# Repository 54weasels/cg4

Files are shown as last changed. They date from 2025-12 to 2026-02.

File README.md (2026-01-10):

# Sun CG/4
From [Frame Buffer History Lesson](https://www.sunhelp.org/faq/FrameBufferHistory.html):
```
cg4: device name: "/dev/cgfour0"  
```
Project name: Prism The dumb 8-bit color frame buffer with overlay and enable planes. Found in 3/110C, 3/60C, 4/110C and 4/150C. This is the first one using the "P4" bus.

The 10-bit deep frame buffer found on the CPU board of the Sun-3/110, and as an option to the Sun-3/60 and Sun-4/110. The 10 bits on the frame buffer are: 8-bits color frame buffer, 1 bit monochrome frame buffer and 1 bit enable plane, which determines which bits of the colour and mono planes are displayed.

For a Sun-4/110, Sun-3/60 and other machines with a P4 connector the CG4 frame buffer is a daughter-board. Note that no GP can be added to the CG4. There is no rasterop hardware on the CG4 frame buffer. The CG4 will "probably" be on all desktop P4 type products. The device driver for the CG4 is called "cgfour".

```
device cgfour0 at obmem 7 csr 0xff300000 priority 4  
```
This is the P4 bus color frame buffer for the 3/60 and 4/110

Resolution is **1152x900**

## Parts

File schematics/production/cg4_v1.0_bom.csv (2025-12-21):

Designator | Footprint | Quantity | Value | LCSC Part #
C1, C10, C11, C12, C13, C1306, C14, C15, C16, C17, C18, C19, C2, C20, C21, C22, C23, C24, C25, C26, C27, C28, C29, C3, C30, C31, C32, C33, C34, C35, C36, C37, C38, C39, C4, C40, C5, C6, C7, C8, C9 | C_Rect_L7.0mm_W2.0mm_P5.00mm | 41 | 0.1uF
C1300, C1302, C1303, C1305 | C_Rect_L7.0mm_W2.0mm_P5.00mm | 4 | 0.01 uF
J7 | DSUB-15-HD_Socket_Horizontal_P2.29x2.54mm_EdgePinOffset8.35mm_Housed_MountingHolesOffset10.89mm | 1 | DE15_Socket_HighDensity
K1300 | CP_Radial_D10.0mm_P5.00mm | 1 | 10uF
L1300, L1301 | R_Axial_DIN0309_L9.0mm_D3.2mm_P12.70mm_Horizontal | 2 | L_Small
P4 | DIN41612_R_3x32_Male_Vertical_THT | 1 | DIN41612_03x32_C_Split
R1 | R_Axial_DIN0207_L6.3mm_D2.5mm_P10.16mm_Horizontal | 1 | 0 Ω
R1300 | R_Axial_DIN0207_L6.3mm_D2.5mm_P10.16mm_Horizontal | 1 | 500Ω 1%
R1301 | R_Axial_DIN0207_L6.3mm_D2.5mm_P10.16mm_Horizontal | 1 | 1K 1%
R1302, R1303, R1304 | R_Axial_DIN0207_L6.3mm_D2.5mm_P10.16mm_Horizontal | 3 | 75Ω 1%
R1311, R1312, R1313, R5 | R_Axial_DIN0207_L6.3mm_D2.5mm_P10.16mm_Horizontal | 4 | 330Ω
R1315 | R_Axial_DIN0207_L6.3mm_D2.5mm_P10.16mm_Horizontal | 1 | ? Ω
S1000 | R_Array_SIP10 | 1 | 470Ω
U1000, U1006 | DIP-20_W7.62mm | 2 | PAL16R8
U1001, U1002, U1003 | DIP-24_W7.62mm | 3 | PAL20X10
U1004 | DIP-24_W7.62mm | 1 | PAL20R6
U1005, U1008, U1009, U1010 | DIP-20_W7.62mm | 4 | P16L8
U1007 | DIP-24_W7.62mm | 1 | P20L8
U1015 | DIP-16_W7.62mm | 1 | 74F175
U1016 | DIP-20_W7.62mm | 1 | 74F244
U1017, U1021, U1036, U1037, U1038, U1104, U1105, U1114 | DIP-16_W7.62mm | 8 | 330Ω
U1100, U1101, U1102, U1103, U1110, U1111, U1112, U1113 | DIP-16_W7.62mm | 8 | 74F257
U1129 | DIP-14_W7.62mm | 1 | 74LS393
U1200, U1201, U1202, U1203, U1204, U1205, U1206, U1207, U1208, U1209, U1210, U1211, U1212, U1213, U1214, U1215, U1216, U1217, U1218, U1219, U1220, U1221, U1222, U1223, U1224, U1225, U1226, U1227, U1228, U1229, U1230, U1231, U1300, U1301, U1302, U1303, U1304, U1305, U1306, U1307 | ZIP_24 | 40 | HM53461
U1310 | PGA_84_Pin | 1 | BT458
U1311 | Oscillator_DIP-14 | 1 | 92.9405Mhz
U1312 | DIP-16_W7.62mm | 1 | 10H101
U1313 | DIP-16_W7.62mm | 1 | 10H131
U1314 | DIP-16_W7.62mm | 1 | 10H350
U1315 | TO-92_Inline | 1 | LM385BZ-1.2
U1318 | DIP-14_W7.62mm | 1 | 74F08

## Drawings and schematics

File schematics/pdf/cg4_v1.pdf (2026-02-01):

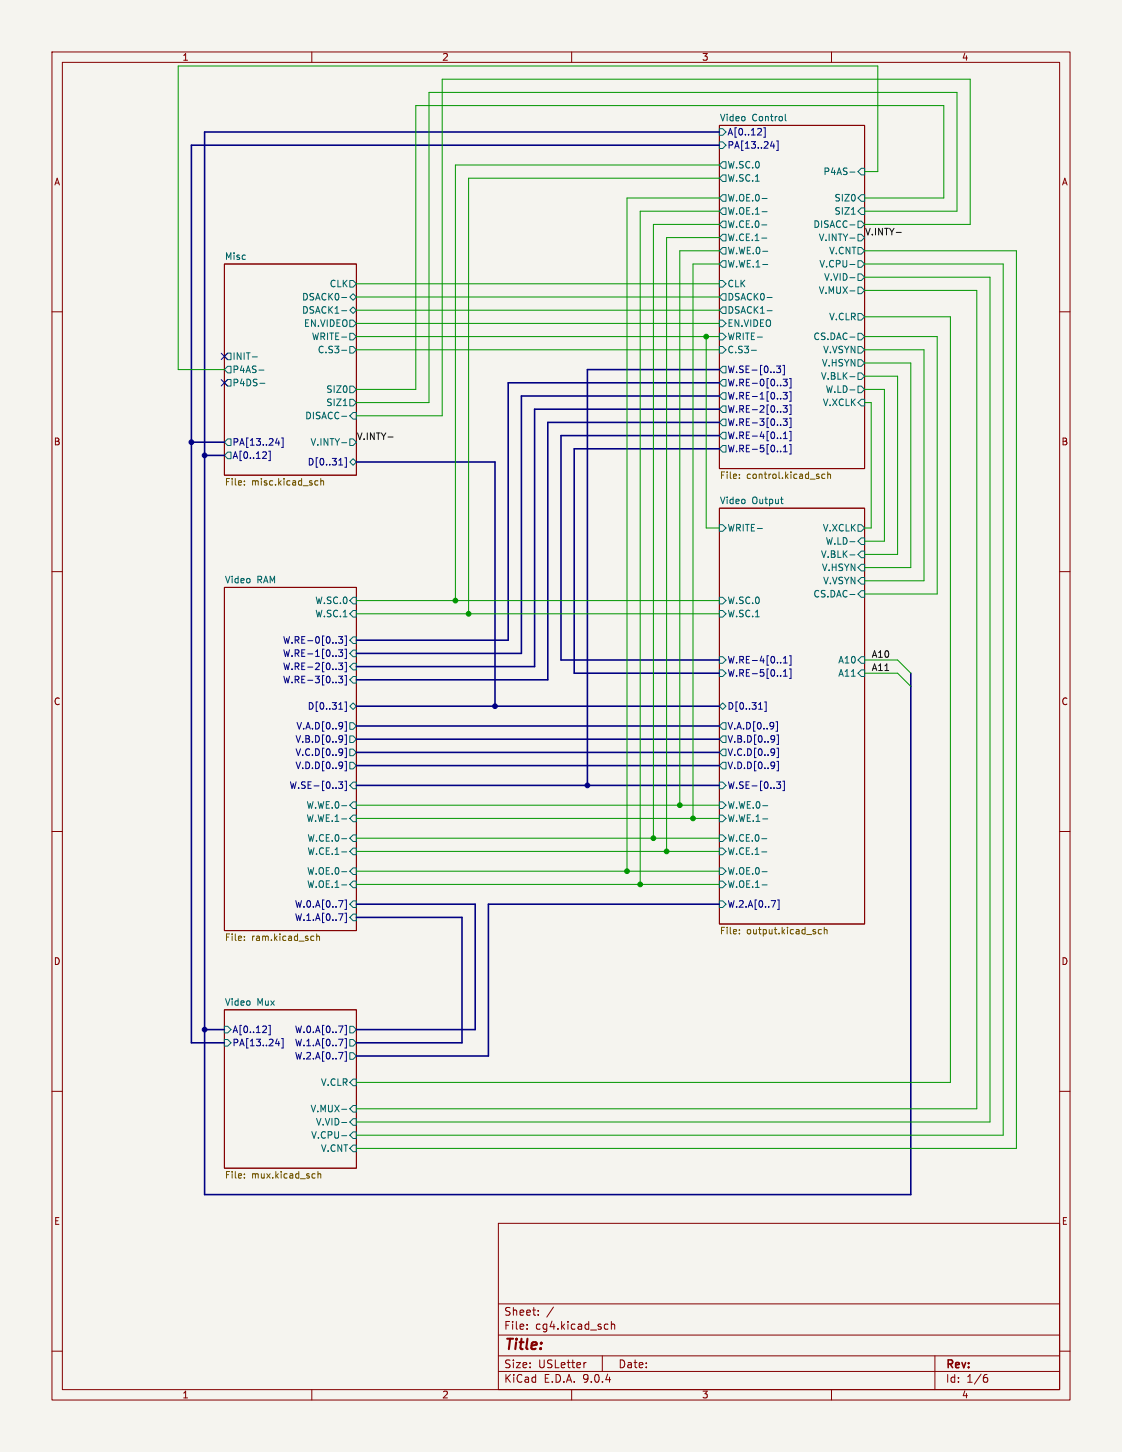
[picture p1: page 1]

V.VSYN
W.RE-5[0..1] W.SC.0 W.SC.1 Video Output File: output.kicad_sch

V.D.D[0..9] Video RAM

Id: 1/6 Title: File: cg4.kicad_sch Sheet: / V.CLR W.0.A[0..7]

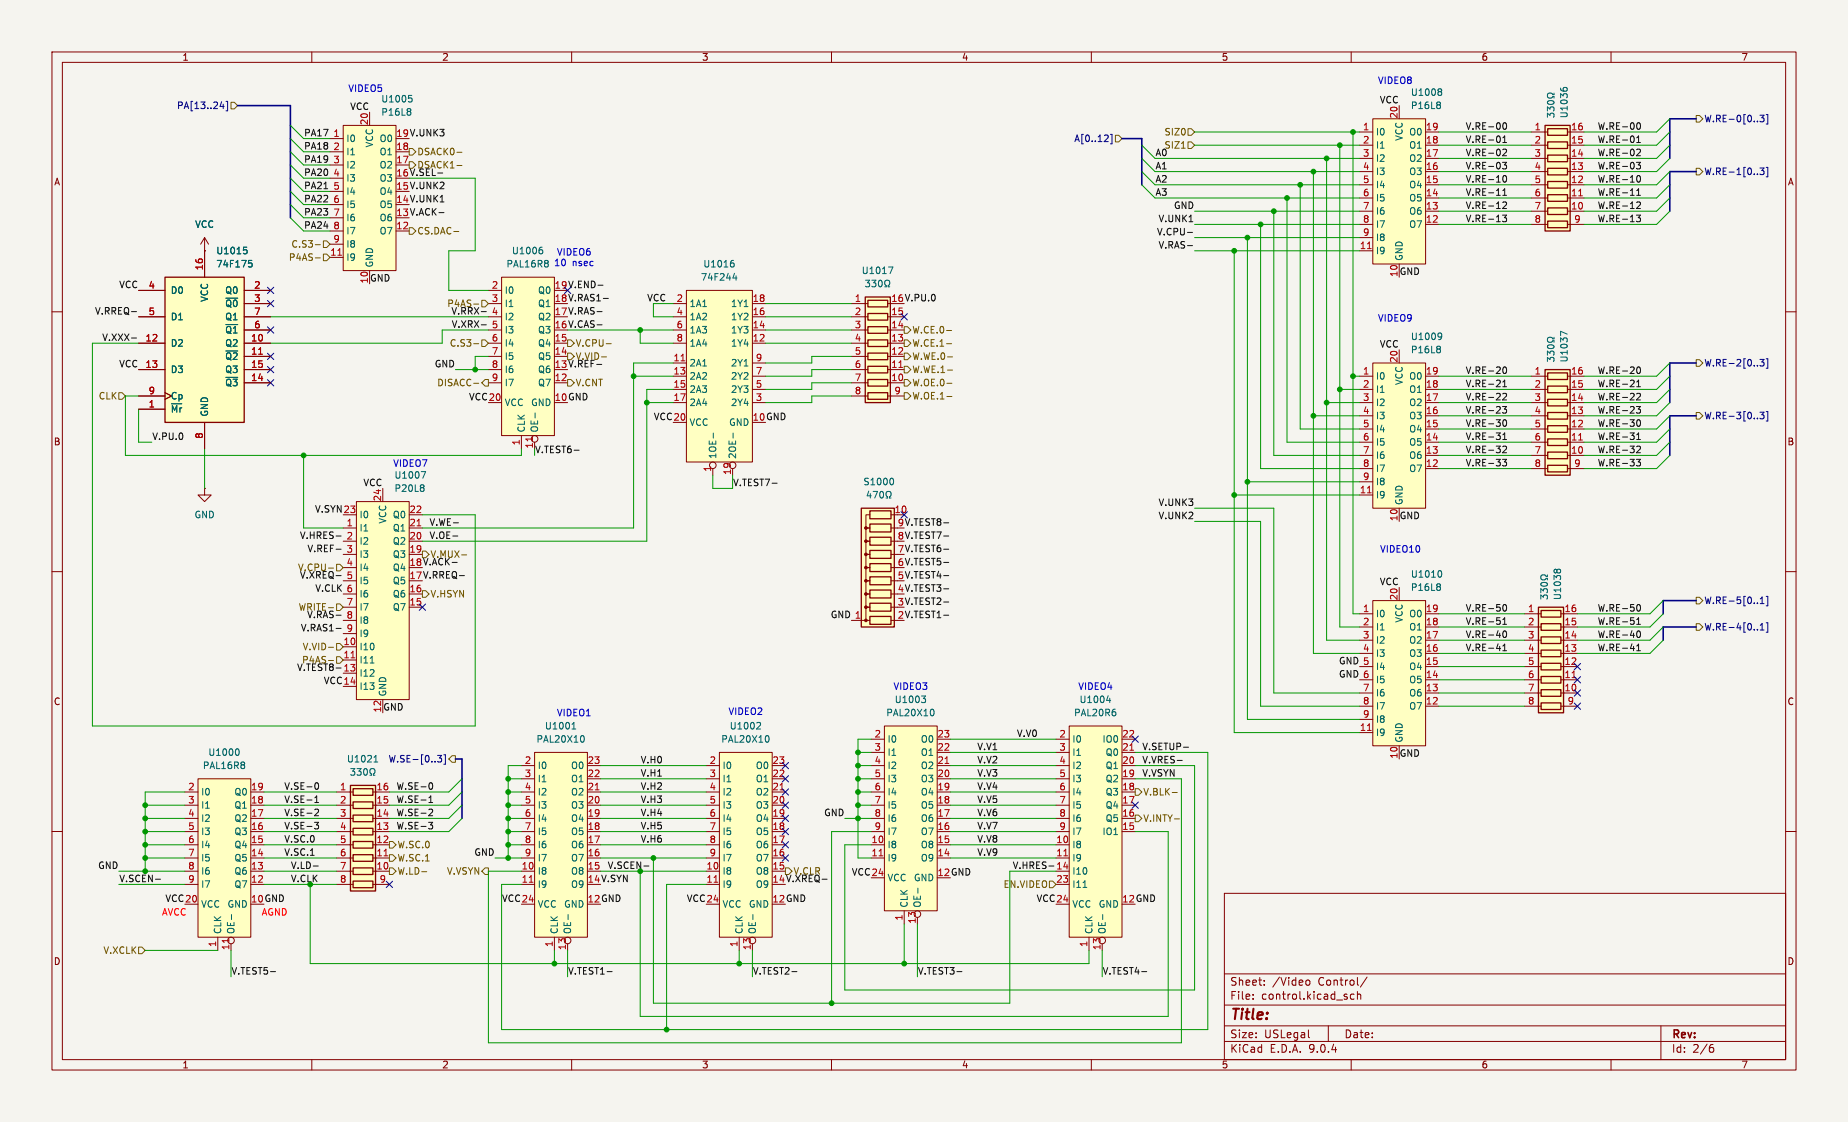
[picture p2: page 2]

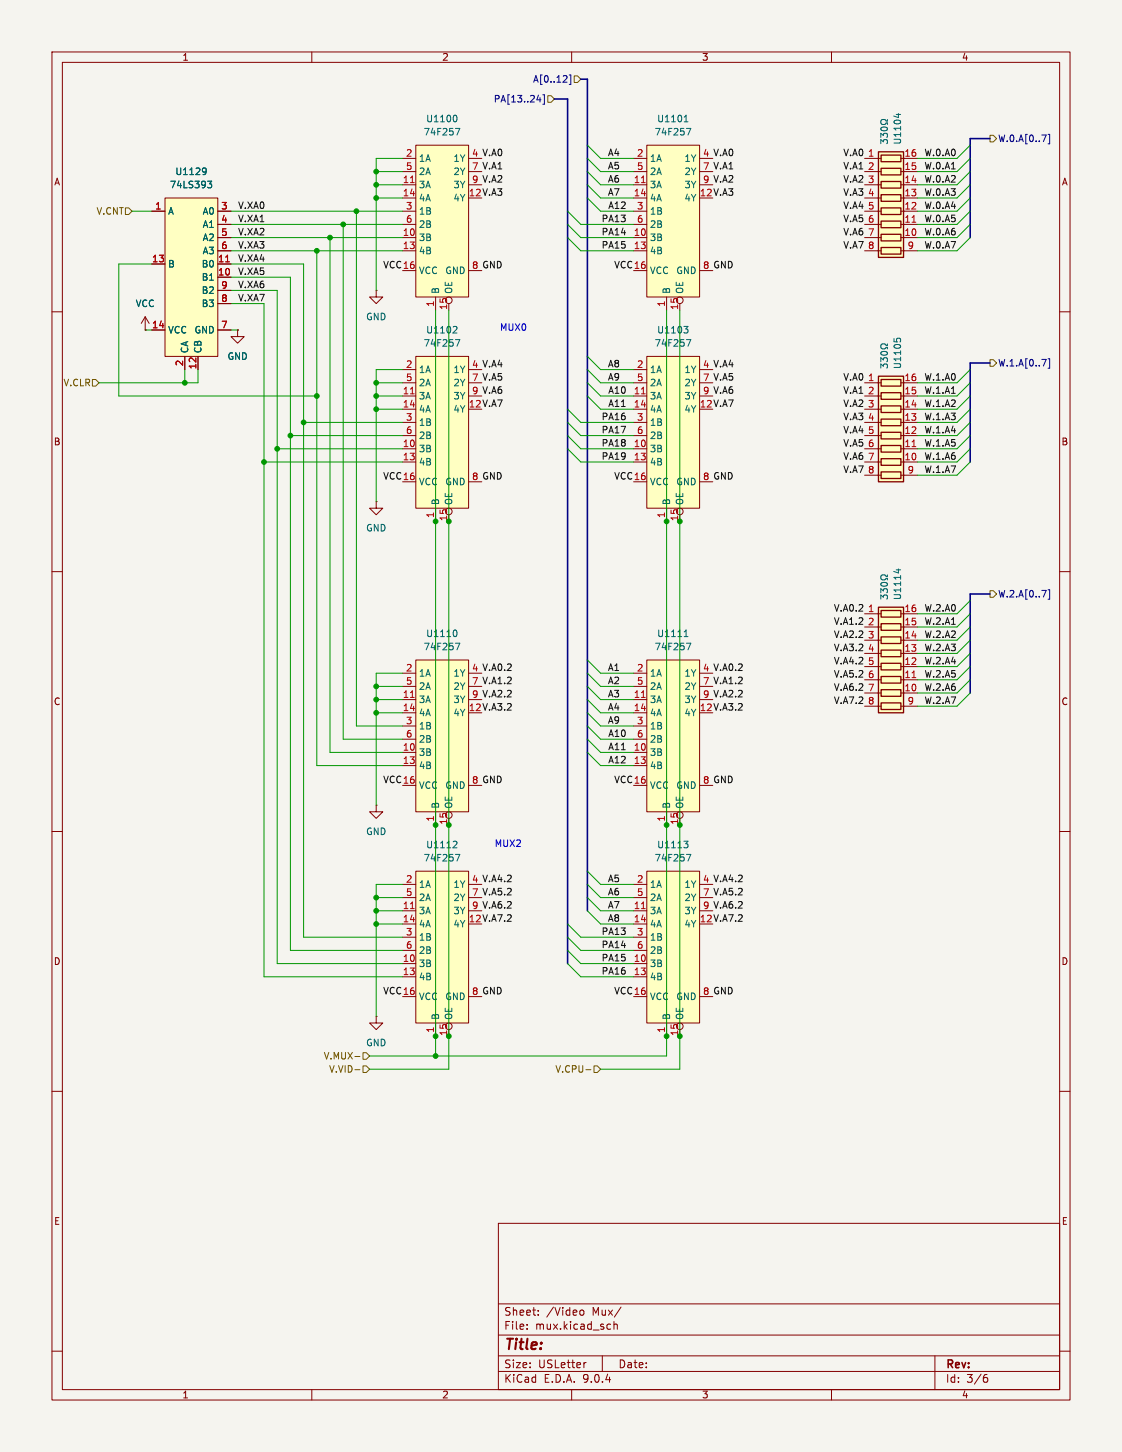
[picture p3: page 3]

2 CB 12 A0 3 A1 4 A2 5 A3 6 B0 11 B1 10 B2 9 B3 8 GND 7 VCC GND

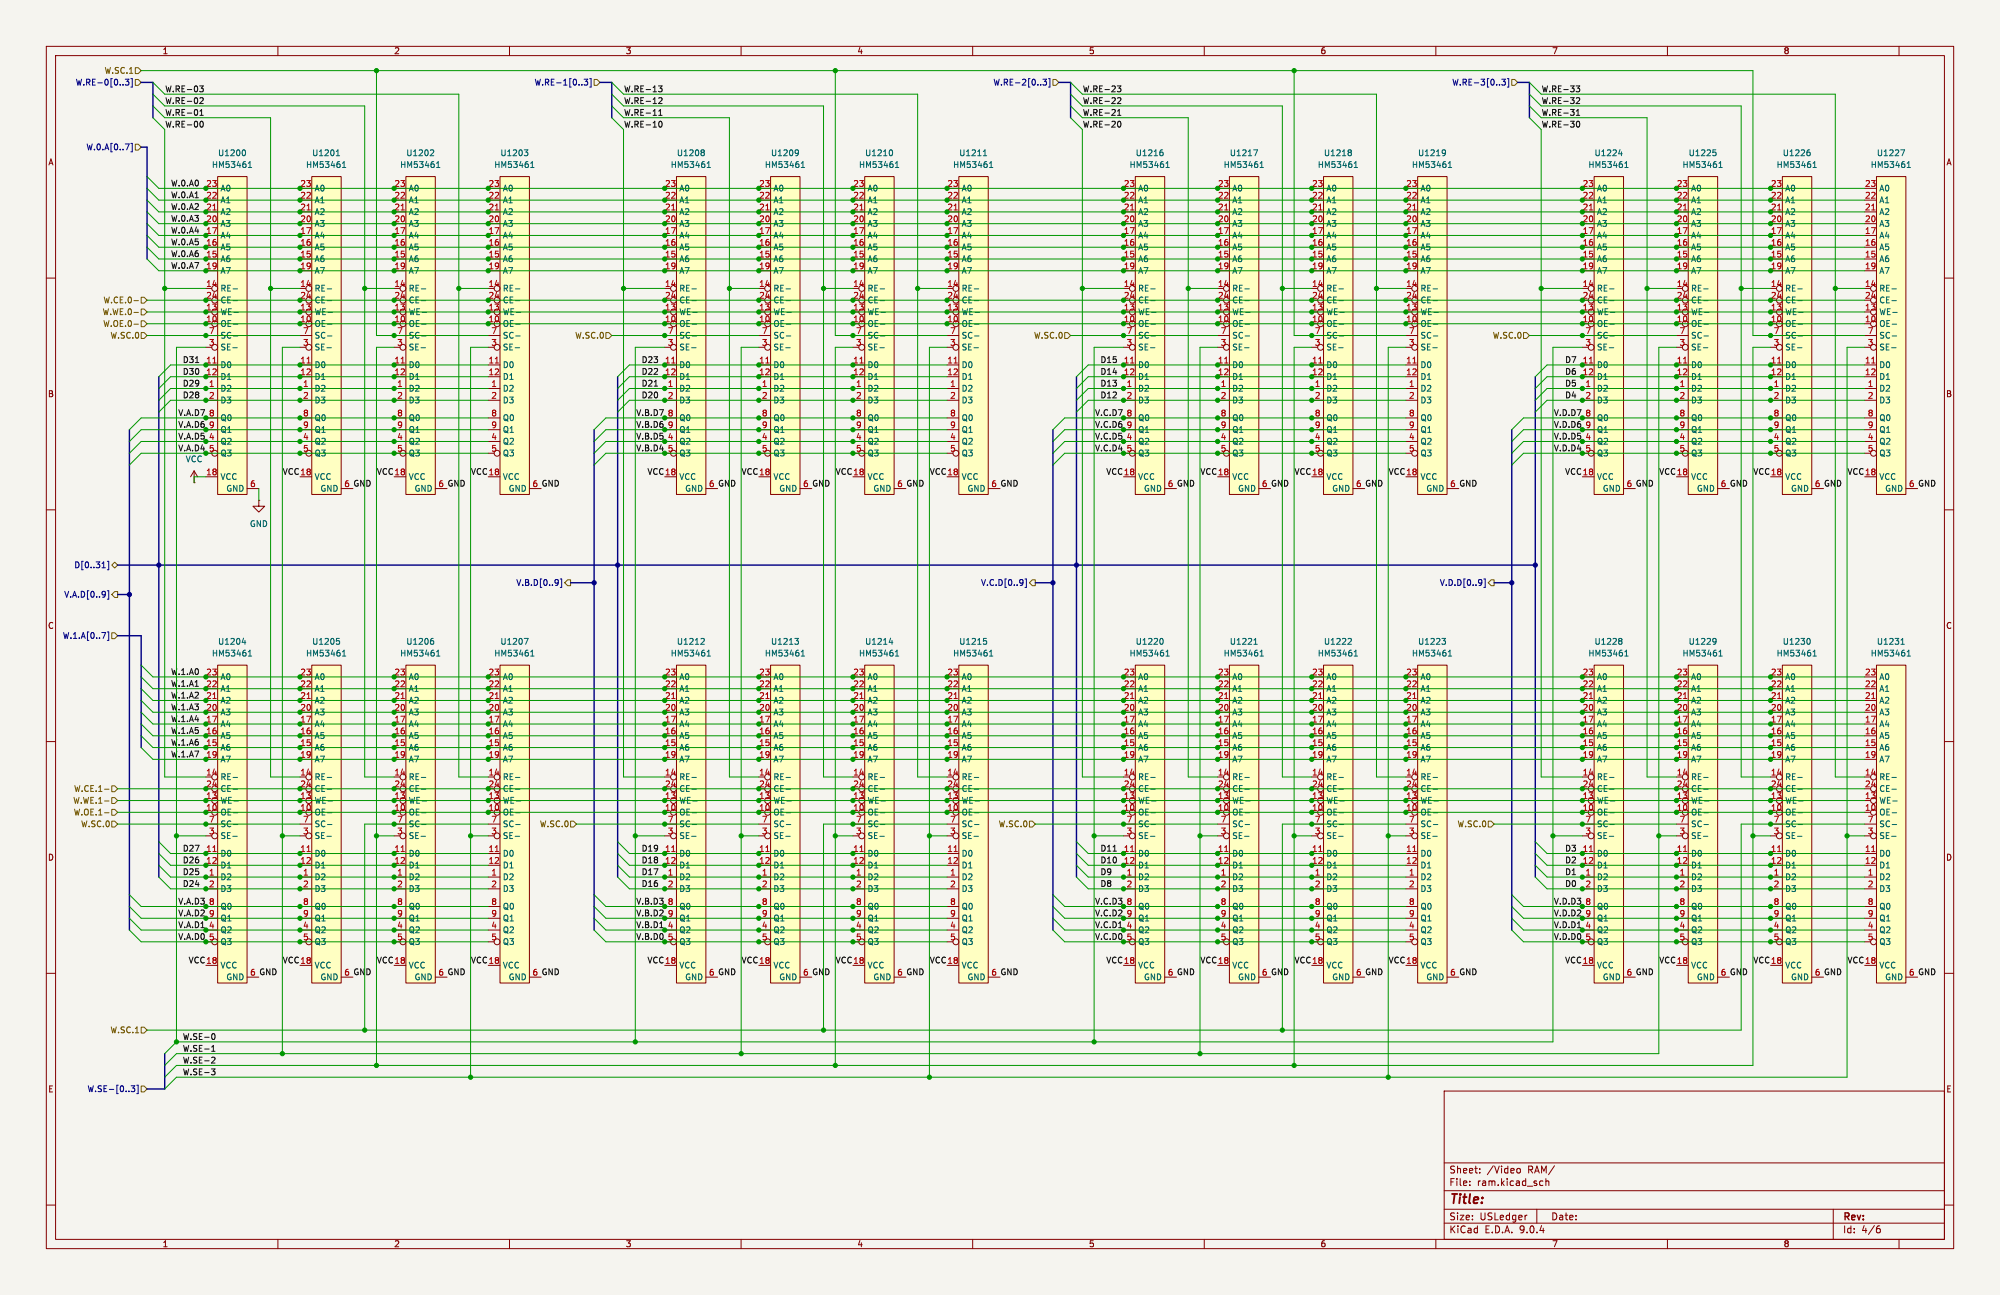
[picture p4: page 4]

6 U1230 HM53461 A0 23 A1 22 A2 21 A3 20 A4 17 A5 16 A6 15 A7 19 RE- 14 CE- 24 WE- 13 OE- 10 SC- 7 SE- 3 D0 11 D1 12 D2 1 D3 2 Q0 8 Q1 9 Q2 4 Q3 5 VCC 18 GND 6 U1223 HM53461 A0 23 A1 22 A2 21 A3 20 A4 17 A5 16 A6 15 A7 19 RE- 14 CE- 24 WE- 13 OE- 10 SC- 7 SE- 3 D0 11 D1 12 D2 1 D3 2 Q0 8 Q1 9 Q2 4 Q3 5 VCC 18 GND 6 U1204 HM53461

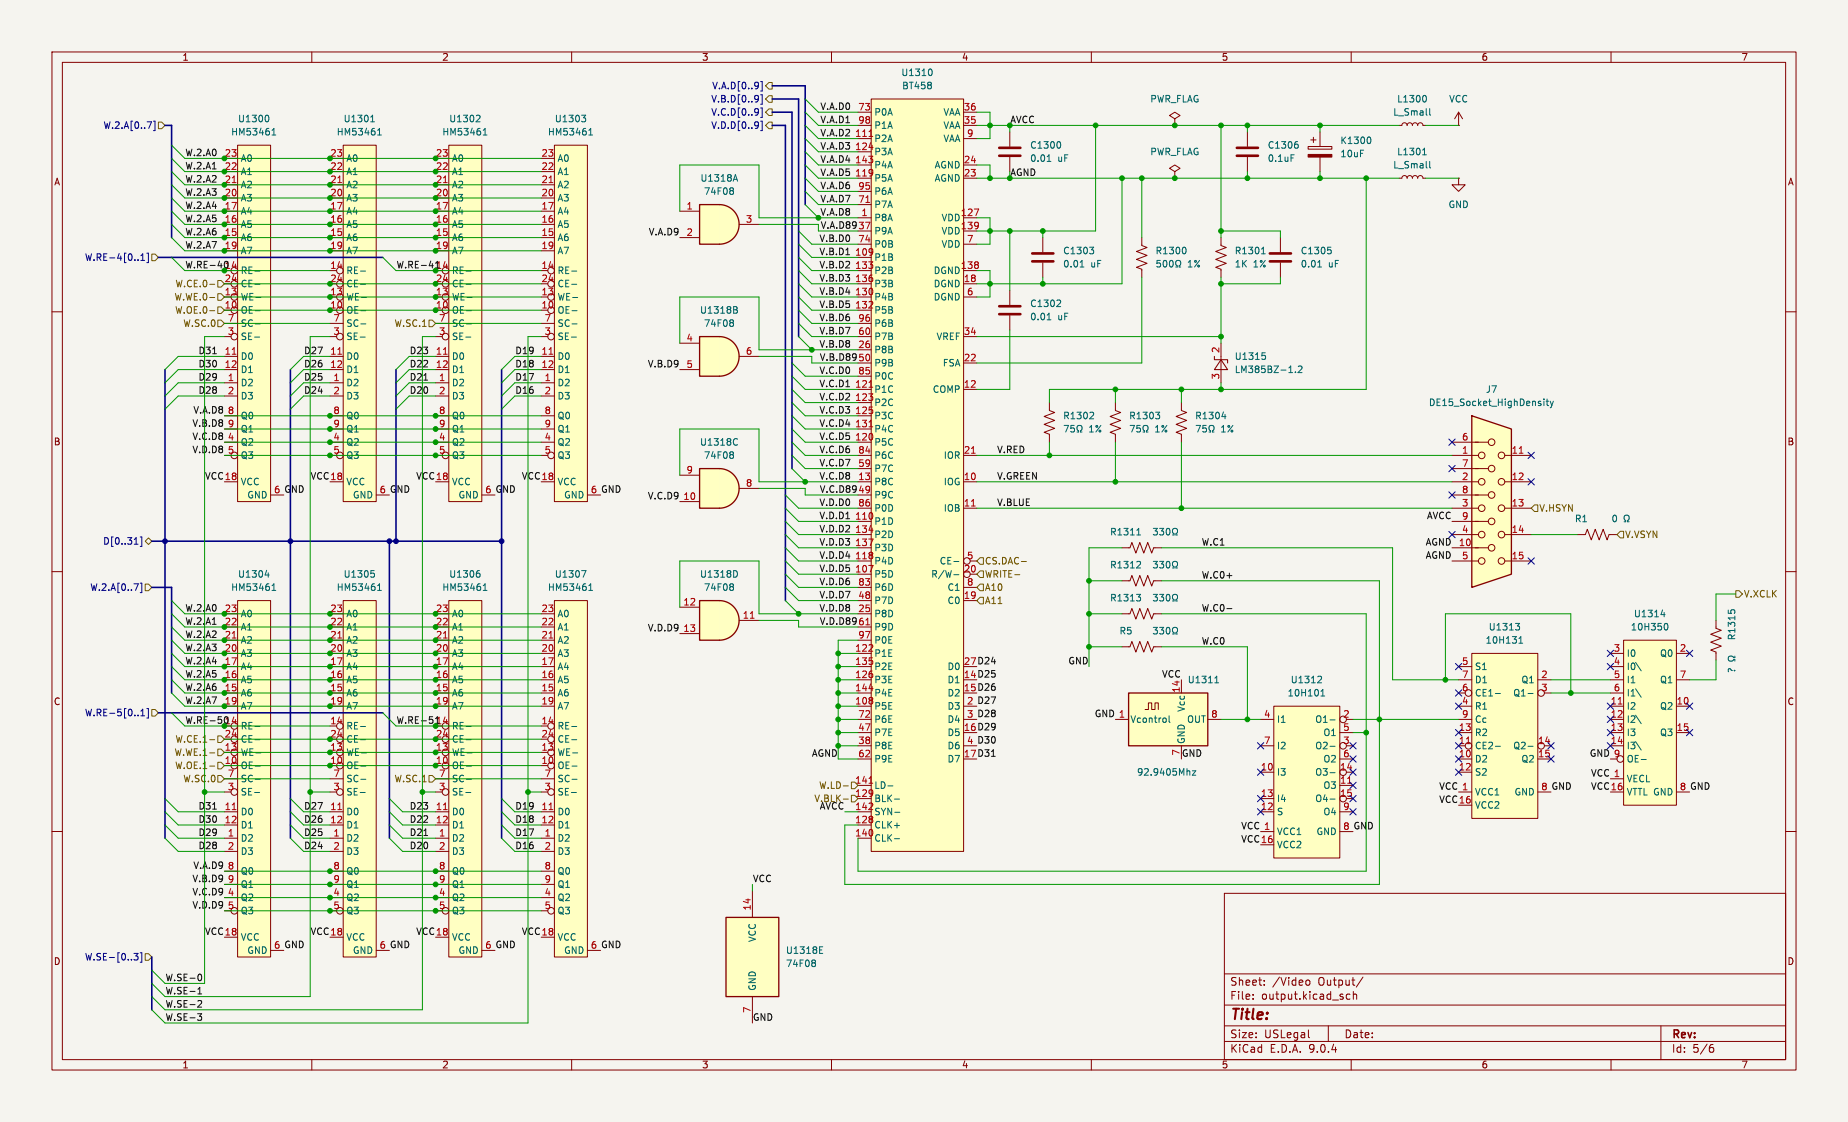
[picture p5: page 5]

VAA 36 VAA 35 VAA 9 AGND 24 AGND 23 VDD127 VDD139 VDD 7 DGND138 DGND 18 DGND 6 VREF 34 FSA 22 COMP 12

LD- 141 BLK- 129 SYN- 142 CLK+ 128 CLK- 140

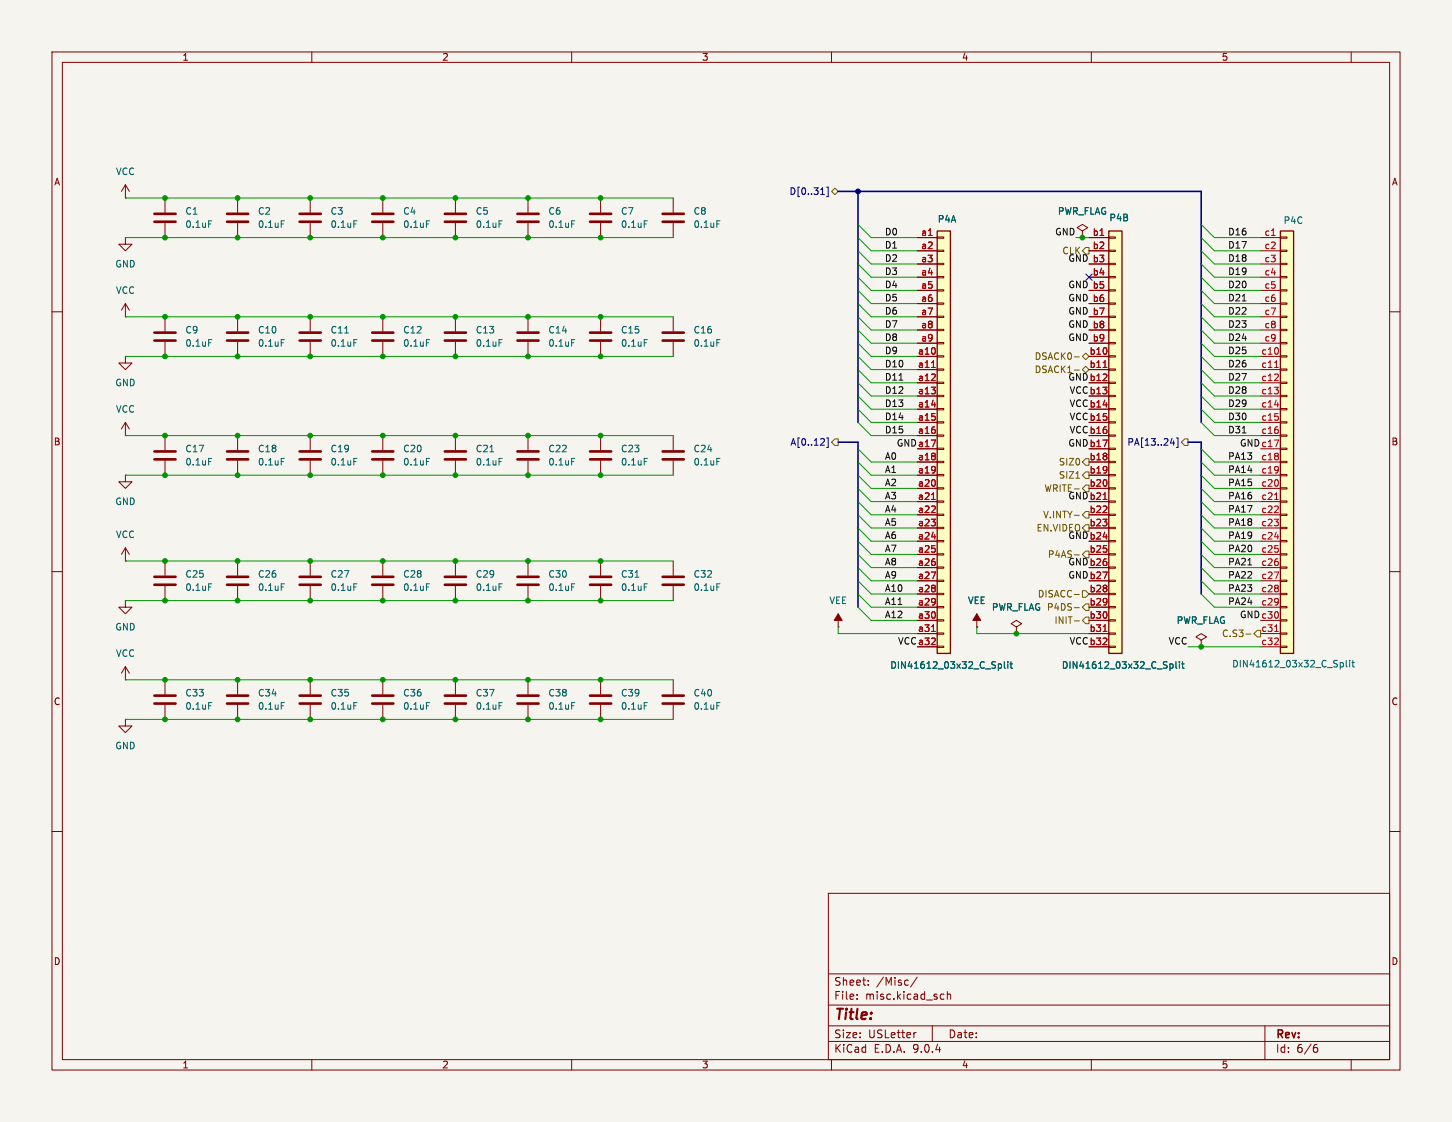
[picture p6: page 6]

Id: 6/6 Title: File: misc.kicad_sch Sheet: /Misc/

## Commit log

2025-09-27 First commit for sun 3/60 CG4 color video board on the P4 bus. Mostly has the RAM section filled in, and some high-level components.
    [cg4.kicad_pcb, cg4.kicad_sch, control.kicad_sch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]
2025-09-29 Fill in more output section
    [cg4.kicad_sch, output.kicad_sch, ram.kicad_sch]
2025-10-13 Populate misc page with P4 connector and caps Finish MUX, RAM and most of Output Lots of progress on Control Lay out root and connect most components
    [cg4.kicad_sch, control.kicad_sch, misc.kicad_sch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]
2025-10-17 Fill in most of control, wire up addresses, and more
    [cg4.kicad_sch, control.kicad_sch, mux.kicad_sch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]
2025-10-18 Add datasheets
    [control.kicad_sch]
2025-10-19 First initial layout, fix ZIP footprint.
    [cg4.kicad_pcb, control.kicad_sch, mux.kicad_sch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]
2025-10-28 Fix layout of the memory chips based on the board Fix the orientation of the P4 connector Connect CS.DAC- based on the board Change the orientation of the ECL resistors to route better Fix the copper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
    [cg4.kicad_pcb, cg4.kicad_sch, control.kicad_sch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]
2025-11-17 Fix the schematics as per the tracing of the actual board. fork a layout with the original positioning. New version PCB that should make routing easier.
    [cg4.kicad_pcb, cg4.kicad_sch, cg4_6layer.kicad_pcb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]
2025-11-22 More fixes from the physical board tracing. Playing around with layouts: main "cg4" layout is relaxed so it can autoroute. 6layer is the original layout, and the ram_routed is a partial/manually rout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
    [cg4.kicad_pcb, cg4_6layer.kicad_pcb, cg4_ram_routed.kicad_pcb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]
2025-11-30 Fix ERCs which uncovered some issues with W.RE for the overlay memory. Finish the ECL chips for clock control - need to find value of R1315. Add space for 0-ohm resistor on V.VSYN which exists in sch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
    [cg4.kicad_sch, control.kicad_sch, output.kicad_sch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]
2025-12-08 Finish routing and misc fixes in the analog section
    [cg4.kicad_pcb, control.kicad_sch, misc.kicad_sch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]
2025-12-08 Clean up
    [cg4.kicad_pcb]
2025-12-08 More clean-up
    [cg4.kicad_pcb]
2025-12-20 Add the missing PAL image. PALs were tested in the original and all work.
    [cg4.kicad_pcb]
2025-12-21 Put ECL clock on an island for GND/VCC
    [cg4.kicad_pcb]
2025-12-21 Add back reference silkscreen, name the board
    [cg4.kicad_pcb]
2025-12-21 First version production files
    [cg4_v1.0_bom.csv, cg4_v1.0_designators.csv, cg4_v1.0_positions.csv]
2026-02-01 Add schematics plot for v1
